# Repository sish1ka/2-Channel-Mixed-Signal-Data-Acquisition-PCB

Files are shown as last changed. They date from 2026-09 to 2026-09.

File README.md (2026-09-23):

# 2-Channel-Mixed-Signal-Data-Acquisition-PCB

## Overview

This project involves the design of a 2-channel mixed-signal data acquisition system intended to measure 0–5 V analog signals and convert them into digital data for microcontroller-based processing and analysis.

Each analog input passes through input protection, voltage scaling, buffering, and active low-pass filtering before being sampled by a 12-bit ADC on an STM32 microcontroller.

The system is being designed and simulated using LTspice and will be implemented as a 2-layer PCB using KiCad. In the future, Embedded C will be used for microcontroller data acquisition and MATLAB will be used for data analysis.

## Objectives

* Design a 2-channel analog data acquisition system
* Accept 0–5 V analog input signals
* Scale the input signals to an ADC-compatible voltage range
* Implement input protection against abnormal voltage excursions
* Buffer the analog signals to minimize loading between circuit stages
* Implement 2nd-order active low-pass filtering
* Sample the conditioned signals using a 12-bit ADC
* Transfer acquired data through UART
* Verify circuit behavior through simulation
* Design and verify a 2-layer PCB
* Analyze acquired data using MATLAB

## Tools

* LTspice
* KiCad
* C
* MATLAB
* Git / GitHub

## Circuit Design

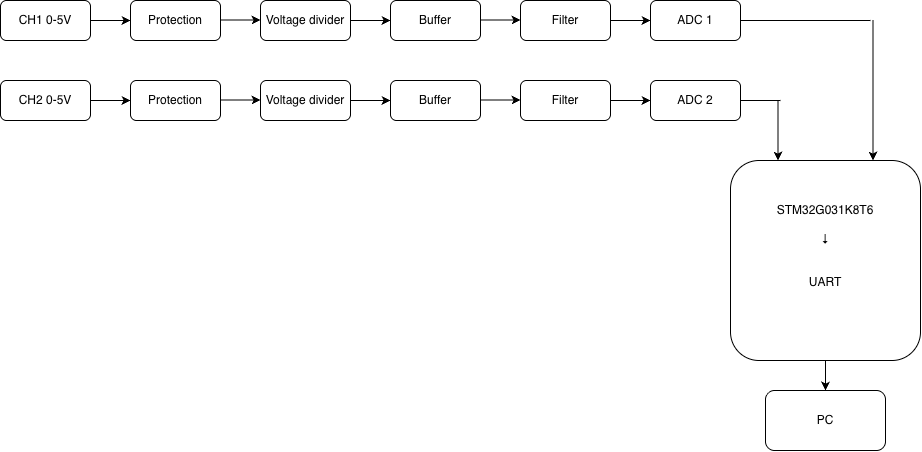
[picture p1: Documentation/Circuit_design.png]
Circuit Design


## Design Summary

| Parameter | Value |
| --- | ---: |
| Number of channels | 2 |
| Input signal | 0–5 V |
| ADC voltage range | 0–3.3 V |
| ADC resolution | 12-bit |
| Sampling rate | 4 kS/s/channel |
| Useful bandwidth | 0–100 Hz |
| Low-pass filter | 2nd-order Sallen-Key |
| Filter cutoff | ~297 Hz |
| Nominal system gain | ~0.60 V/V |
| Maximum nominal ADC input | ~3.0 V |
| Microcontroller | STM32G031K8T6 |
| Analog op-amp | MCP6004 |
| PCB layers | 2 |
| PCB dimensions | ~80 × 50 mm |
| UART baud rate | 460800 baud |z

## LTspice Simulation

### Verification Procedure

The analog front end is being verified using a node-by-node transient analysis.

Each verification step checks a specific electrical condition before proceeding to the next stage.

### 1. Voltage divider

**Purpose:**
Verify that the input protection resistor and voltage divider produce the expected scaled voltage for a 0–5 V input signal.

**Circuit Configuration:**

| Component | Value |
| --- | ---: |
| Input protection resistor | 1 kΩ |
| R_TOP | 16.5 kΩ |
| R_BOTTOM | 10 kΩ |

**Test Signal:**

```text
SINE(2.5 2.5 10)
```

The input signal has a 2.5 V DC offset, 2.5 V amplitude, and 10 Hz frequency, resulting in a 0–5 V input waveform.

**Transient Analysis:**

```text
.tran 100m
```

The 100 ms simulation window corresponds to one complete cycle of the 10 Hz input signal.

**Procedure:**

1. Apply the 0–5 V test signal to the input.
2. Run a transient analysis for 100 ms in LTspice.
3. Probe the input node.
4. Confirm that the input signal ranges from 0 V to 5 V.
5. Probe the output of the voltage divider.
6. Confirm that the scaled signal ranges from approximately 0 V to 1.82 V.

**Expected Result:**

| Parameter | Expected |
| --- | ---: |
| Input minimum | 0 V |
| Input maximum | 5 V |
| Scaled output minimum | ~0 V |
| Scaled output maximum |  ~1.82 V |

**Measured Result:**
`Vin = 0–5.00 V`
`Vscaled = 0–1.82 V`

**Result:** Pass

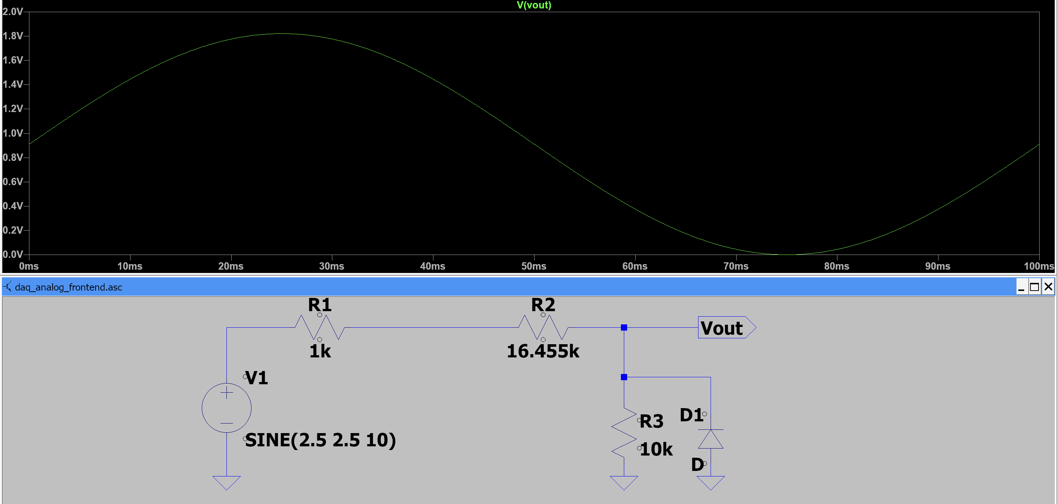
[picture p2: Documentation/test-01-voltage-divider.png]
Voltage Scaling Verification


### 2. Diode Voltage Protection Verification

**Purpose:**
Verify that the protection diode limits abnormal negative voltage excursions at the scaled node.

A bipolar test signal is applied to intentionally drive the input below the normal 0–5 V operating range.

**Test Signal:**

```text
SINE(0 5 10)
```

This produces a −5 V to +5 V input waveform.

**Procedure:**

1. Apply the bipolar test signal to the input.
2. Run a transient analysis for 100 ms in LTspice.
3. Probe the scaled node.
4. Observe the negative voltage excursion without the protection diode.
5. Enable the protection diode.
6. Repeat the simulation.
7. Compare the negative voltage excursion with and without the diode.

**Expected Result:**

The protection diode should conduct during the negative voltage excursion and limit the negative voltage at the protected node.

**Measured Result:**
Without the diode, the scaled node follows the negative input excursion. With the diode connected, the negative voltage is clamped and the scaled node no longer follows the negative excursion below the diode's forward-voltage region.

**Result:** Pass

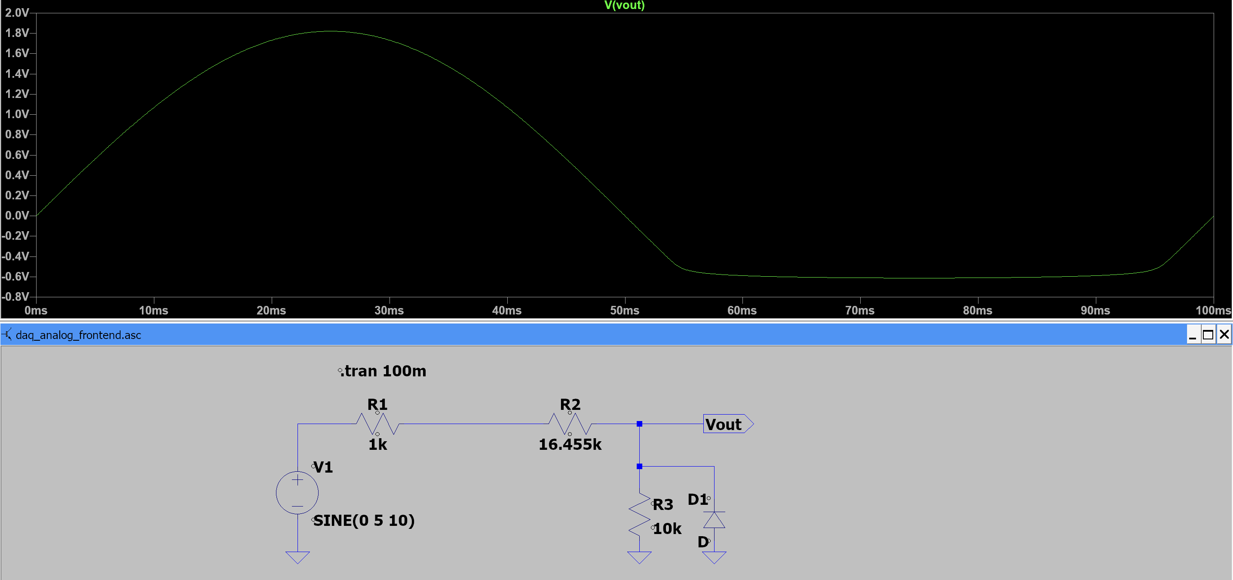
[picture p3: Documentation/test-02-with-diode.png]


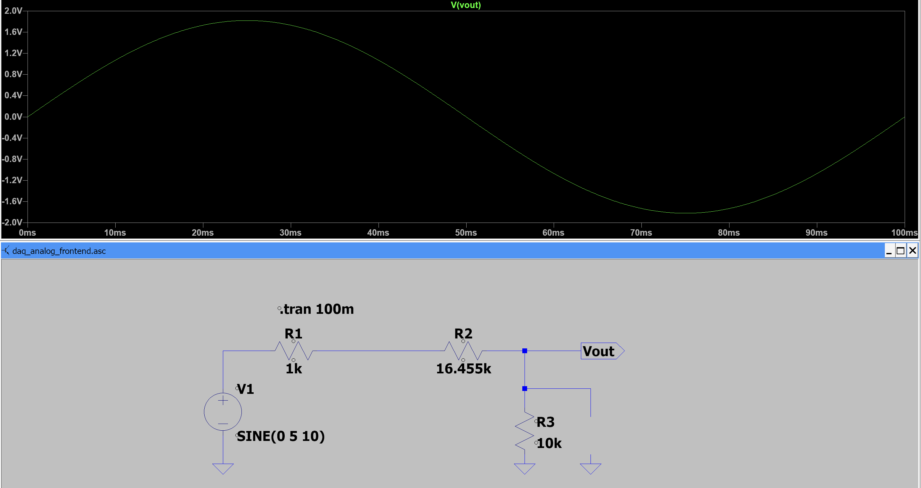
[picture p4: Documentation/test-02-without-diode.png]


### 3. Buffer Verification

**Purpose:**
Verify that the voltage buffer reproduces the scaled input signal without significantly changing its voltage level. The buffer also isolates the voltage divider from the following filter stage by providing high input impedance and low output impedance.

**Buffer Configuration:**

| Parameter | Value |
| --- | ---: |
| Op-Amp | UniversalOpamp2 |
| Configuration  | Voltage follower |
| Supply voltage | 3.3 V / 0 V |
| Buffer input | Voltage divider output |
| Buffer output  | Filter input |
| Feedback | Output directly connected to inverting input |

**Procedure:**

1. Apply the 0–5 V input signal using `SINE(2.5 2.5 10)`.
2. Run the transient simulation for 100 ms.
3. Measure the voltage at the output of the voltage divider.
4. Measure the voltage at the output of the buffer.
5. Compare the two waveforms over the full input cycle.

**Expected Result:**

The buffer output should closely follow the voltage-divider output with approximately unity voltage gain.

$$
A_v = \frac{V_{OUT}}{V_{IN}} \approx 1
$$

For the 0–5 V input signal, the voltage divider produces approximately 0–1.82 V. Therefore, the buffer output should also be approximately 0–1.82 V.

| Measurement | Expected Result |
| --- | ---: |
| Buffer input minimum  | ~0 V |
| Buffer input maximum  | ~1.82 V |
| Buffer output minimum | ~0 V |
| Buffer output maximum | ~1.82 V |
| Voltage gain | ~1 V/V |

**Measured Result:**

The buffer output closely follows the voltage-divider output. The buffer input and output waveforms overlap over the 0–1.82 V range, confirming that the voltage follower provides approximately unity gain without significantly altering the signal amplitude.

**Result:** Pass

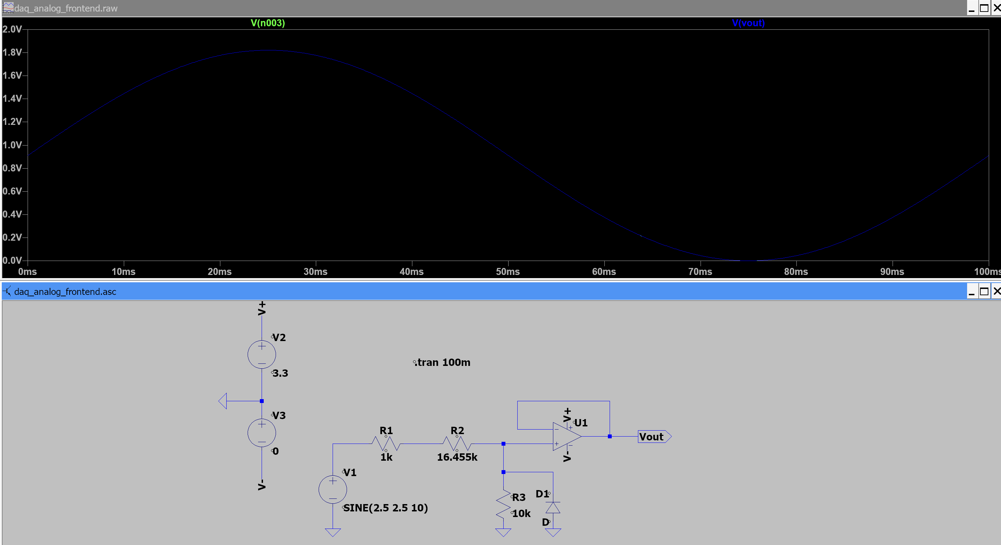
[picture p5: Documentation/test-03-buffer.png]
Buffer Verification


### 4. Sallen-Key Filter Response Verification

**Purpose:**
Verify that the Sallen-Key stage provides the intended second-order low-pass response, including the expected low-frequency gain, cutoff frequency, and roll-off behavior.

**Filter Configuration:**

| Parameter | Value |
| --- | ---: |
| R1 | 5.36 kΩ |
| R2 | 5.36 kΩ |
| C1 | 100 nF |
| C2 | 100 nF |
| Rf | 5.90 kΩ |
| Rg | 10 kΩ |
| Op-Amp Supply | 3.3 V / GND |

**Theoretical Low-Pass Cutoff:**

For equal resistor and capacitor values:

$$
f_c = \frac{1}{2\pi RC}
$$

$$
f_c = \frac{1}{2\pi(5.36\,k\Omega)(100\,nF)}
\approx 297\,Hz
$$

The Sallen-Key gain is:

$$
K = 1 + \frac{R_f}{R_g}
$$

$$
K = 1 + \frac{5.90\,k\Omega}{10\,k\Omega}
\approx 1.59
$$

The corresponding low-frequency magnitude is:

$$
20\log_{10}(1.59) \approx 4.03\,dB
$$

For a second-order low-pass filter, the cutoff frequency is approximately **3 dB below the passband magnitude**. Therefore, with a passband magnitude of approximately +4 dB, the expected magnitude at the cutoff is approximately +1 dB.

**Procedure:**

1. Set the LTspice input source to:

   * DC value: `2.5 V`
   * AC amplitude: `1 V`
   * AC phase: `0°`
2. Run an AC sweep using:
   `.ac dec 100 1 100k`
3. Plot the filter transfer function:
   `V(FILTER_OUT)/V(BUF_OUT)`
4. Measure the magnitude in the low-frequency passband.
5. Measure the magnitude near the theoretical cutoff frequency of 297 Hz.
6. Verify the expected attenuation beyond the cutoff region.

**Expected Result:**

| Measurement | Expected |
| --- | ---: |
| Low-frequency gain | ~1.59 V/V |
| Low-frequency magnitude | ~+4.03 dB |
| Cutoff frequency | ~297 Hz |
| Magnitude at cutoff | ~+1.03 dB |
| High-frequency roll-off | ~−40 dB/decade |

**Measured Result:**

* At **10 Hz:** approximately **+4 dB**
* At **297 Hz:** approximately **+1 dB**
* The measured response is consistent with the expected second-order low-pass behavior.

**Result:** Pass

The measured passband gain and attenuation at 297 Hz closely match the theoretical response. The filter therefore provides the intended low-pass behavior with a cutoff frequency of approximately 297 Hz.

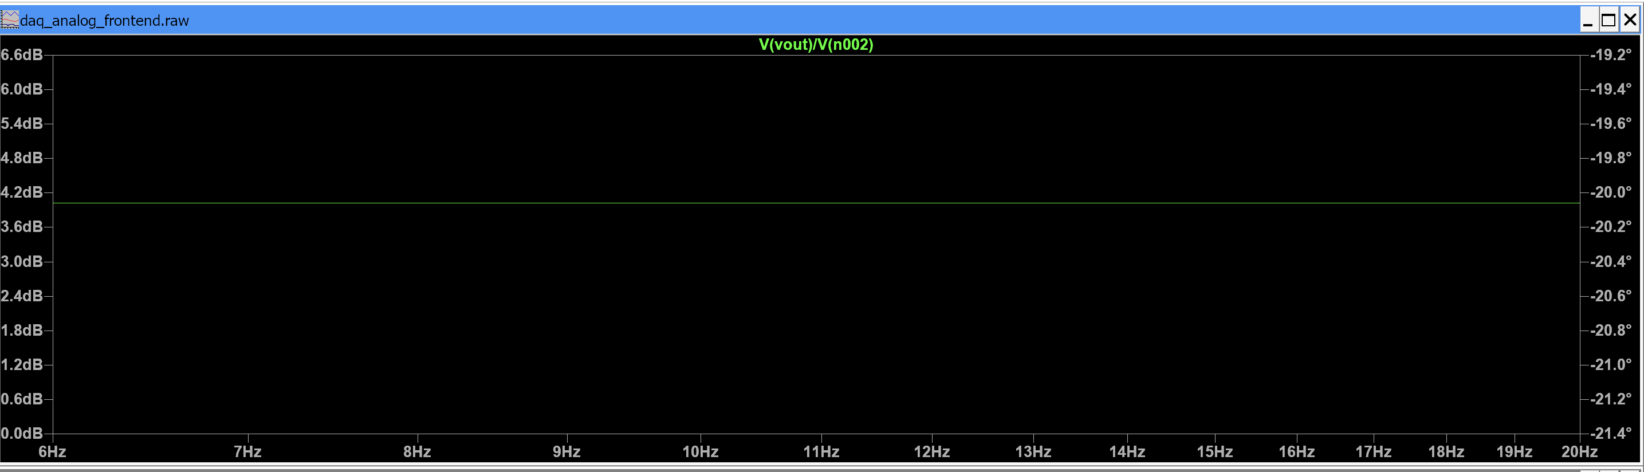
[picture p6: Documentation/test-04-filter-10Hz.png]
Sallen-Key Filter Response

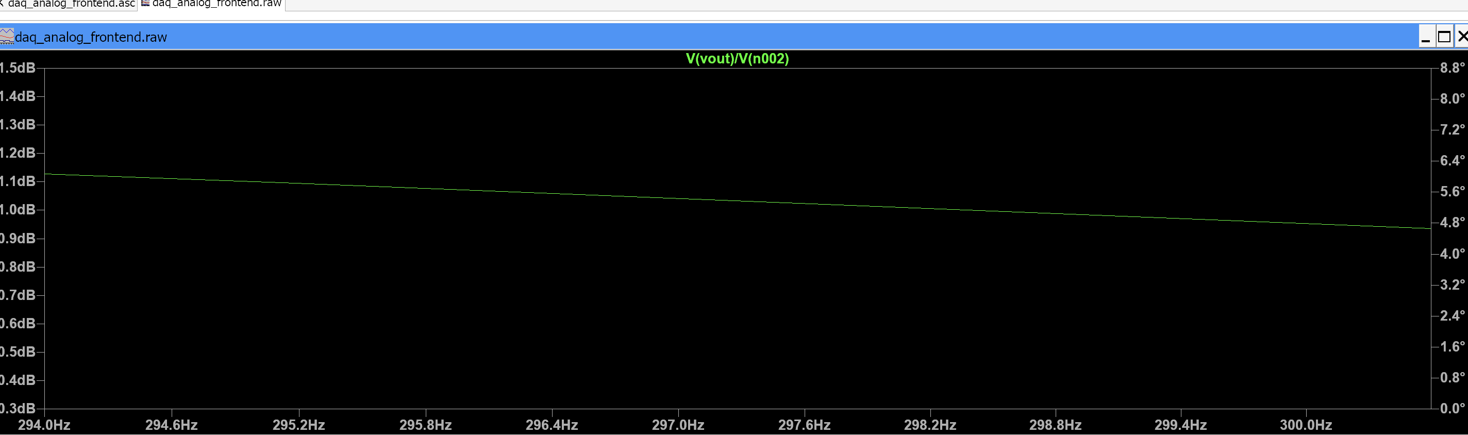
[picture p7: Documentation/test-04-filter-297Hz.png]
Sallen-Key Filter Response


### 5. ADC Input Range Verification

**Purpose:**
Verify that the conditioned analog signal remains within the STM32 ADC input range and that the complete analog front end provides the intended voltage scaling.

**ADC Configuration:**

| Parameter | Value |
| --- | ---: |
| ADC voltage range | 0–3.3 V |
| ADC resolution | 12-bit |
| Input signal | 0–5 V |
| ADC input filter | 47 Ω + 1 nF |
| Expected maximum ADC voltage | ~3.0 V |

**Procedure:**

1. Connect the Sallen-Key filter output to the ADC input through the 47 Ω series resistor.
2. Add a 1 nF capacitor from the ADC input node to GND.
3. Apply a 0–5 V sinusoidal input using:
   `SINE(2.5 2.5 10)`
4. Run a transient simulation using:
   `.tran 100m`
5. Plot the ADC input node voltage, `V(ADC_IN)`.
6. Verify that the ADC input remains within the 0–3.3 V operating range.

**Expected Result:**

For a 5 V maximum input, the nominal analog gain of approximately 0.60 V/V gives:

$$
V_{ADC,max} \approx 5V \times 0.60
$$

$$
V_{ADC,max} \approx 3.0V
$$

The ADC input should therefore remain below the 3.3 V supply while utilizing most of the available ADC range.

**Measured Result:**

The simulated ADC input waveform remained sinusoidal and reached approximately **2.9 V maximum** for a 5 V maximum input.

| Measurement | Result |
| --- | -----: |
| Input minimum | ~0 V |
| Input maximum | 5 V |
| ADC minimum | ~0 V |
| ADC maximum | ~2.9 V |
| ADC supply/reference |  3.3 V |

The maximum ADC voltage is approximately 0.4 V below the 3.3 V supply, providing headroom while maintaining a large usable portion of the ADC input range.

**Result:** Pass

The simulated ADC input remains within the 0–3.3 V range and is suitable for connection to the STM32 ADC.

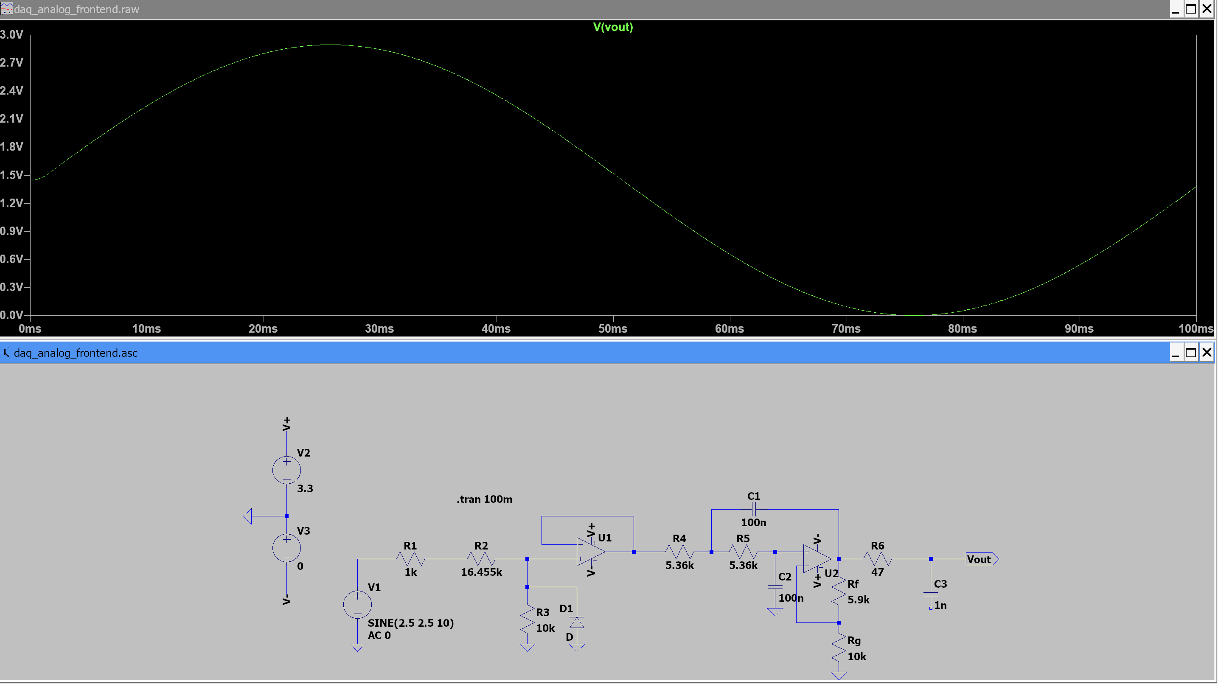
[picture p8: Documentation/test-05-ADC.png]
ADC Input Verification


### Results

| Verification | Theoretical | Measured | Error | Result |
| --- | --- | --- | ----: | --- |
| Voltage scaling | 0–1.89 V | 0–1.89 V | — | Pass |
| Negative voltage protection | Negative excursion clamped | Negative excursion clamped | — | Pass |
| Buffer | Unity gain | Unity gain | — | Pass |
| Filter cutoff | ~297 Hz | ~297 Hz | — | Pass |
| Complete analog chain | 0–3.0 V ADC input | 0–2.9 V ADC input | ~3.3% | Pass |

## PCB Design

The PCB was designed in KiCad based on the verified analog front-end and data acquisition circuit.

The board integrates two analog signal-conditioning channels with input protection, voltage scaling, signal conditioning, filtering, and a STM32G031K8Tx microcontroller interface.

### PCB Layout

* **Board size:** 80 × 50 mm
* **Design software:** KiCad
* **Layers:** 2-layer PCB
* **Analog channels:** 2
* **Main controller:** STM32G031K8Tx
* **Analog front-end:** MCP6004 quad op-amp
* **Mounting:** Through-hole and surface-mount components
* **Design verification:** Electrical Rules Check (ERC) and Design Rules Check (DRC)
* **Manufacturing outputs:** Gerber files and drill files generated from the final PCB layout

### Components

| Ref. | Component | Value | Qty. | Footprint |
| --- | --- | ---: | ---: | --- |
| C1, C2, C4, C5, C7, C8 | Ceramic Capacitor | 100 nF | 6 | `Capacitor_SMD:C_0805_2012Metric` |
| C3, C6 | Ceramic Capacitor | 1 nF | 2 | `Capacitor_SMD:C_0805_2012Metric` |
| D1, D2 | Diode | — | 2 | `Diode_SMD:D_SOD-123` |
| J1, J2 | 2-Pin Header | — | 2 | `Connector_PinHeader_2.54mm:PinHeader_1x02_P2.54mm_Vertical` |
| J3 | 5-Pin Header | — | 1 | `Connector_PinHeader_2.54mm:PinHeader_1x05_P2.54mm_Vertical` |
| J4 | 4-Pin Header | — | 1 | `Connector_PinHeader_2.54mm:PinHeader_1x04_P2.54mm_Vertical` |
| R1, R7 | Resistor | 1 kΩ | 2 | `Resistor_THT:R_Axial_DIN0207_L6.3mm_D2.5mm_P10.16mm_Horizontal` |
| R2, R8 | Resistor | 16.455 kΩ | 2 | `Resistor_THT:R_Axial_DIN0207_L6.3mm_D2.5mm_P10.16mm_Horizontal` |
| R3, R9, R13, Rg1, Rg2  | Resistor | 10 kΩ | 5 | `Resistor_THT:R_Axial_DIN0207_L6.3mm_D2.5mm_P10.16mm_Horizontal` |
| R4, R5, R10, R11 | Resistor | 5.36 kΩ | 4 | `Resistor_THT:R_Axial_DIN0207_L6.3mm_D2.5mm_P10.16mm_Horizontal` |
| R6, R12 | Resistor | 47 Ω | 2 | `Resistor_THT:R_Axial_DIN0207_L6.3mm_D2.5mm_P10.16mm_Horizontal` |
| Rf1, Rf2 | Resistor | 5.9 kΩ | 2 | `Resistor_THT:R_Axial_DIN0207_L6.3mm_D2.5mm_P10.16mm_Horizontal` |
| SW1 | Push Button | — | 1 | `Button_Switch_THT:SW_NKK_GW12LJP` |
| U1 | Quad Op-Amp | MCP6004 | 1 | `Package_DIP:DIP-14_W7.62mm` |
| U2 | Microcontroller | STM32G031K8Tx | 1 | `Package_QFP:LQFP-32_7x7mm_P0.8mm` |

**Total components:** 40

### Connector Pinout

Connector pin assignments are defined in the KiCad schematic.

| Connector | Pins | Function |
| --- | ---: | --- |
| J1 |  1–2 | Channel 1 interface |
| J2 |  1–2 | Channel 2 interface |
| J3 |  1–5 | Microcontroller / system interface |
| J4 |  1–4 | Power / system interface |

> **Note:** Refer to the KiCad schematic for the complete electrical pin assignments and net names.

### Power

The board does not include an onboard voltage regulator. The 3.3 V
rail (STM32 VDD/VDDA, MCP6004 V+) is supplied externally through
**J4 pin 1**, which is expected to be driven directly from a
regulated 3.3 V source — for example, the 3.3 V pin available on
many common USB-to-UART adapters (FTDI FT232RL, CP2102, etc.), or a
bench supply. This was a deliberate simplification to reduce
component count on a first custom board; a future revision could
add an onboard LDO (e.g. AMS1117-3.3) to accept a single unregulated
5 V input instead.

### Circuit Parameters

| Parameter | Value |
| --- | ---: |
| Supply Voltage | +3.3 V |
| Input Range | 0–5 V |
| ADC Range | 0–3.3 V |
| Sampling Rate | 4 kS/s/channel |
| Filter | 2nd-order Sallen-Key |
| Cutoff Frequency | ~297 Hz |

### KiCAD schematic

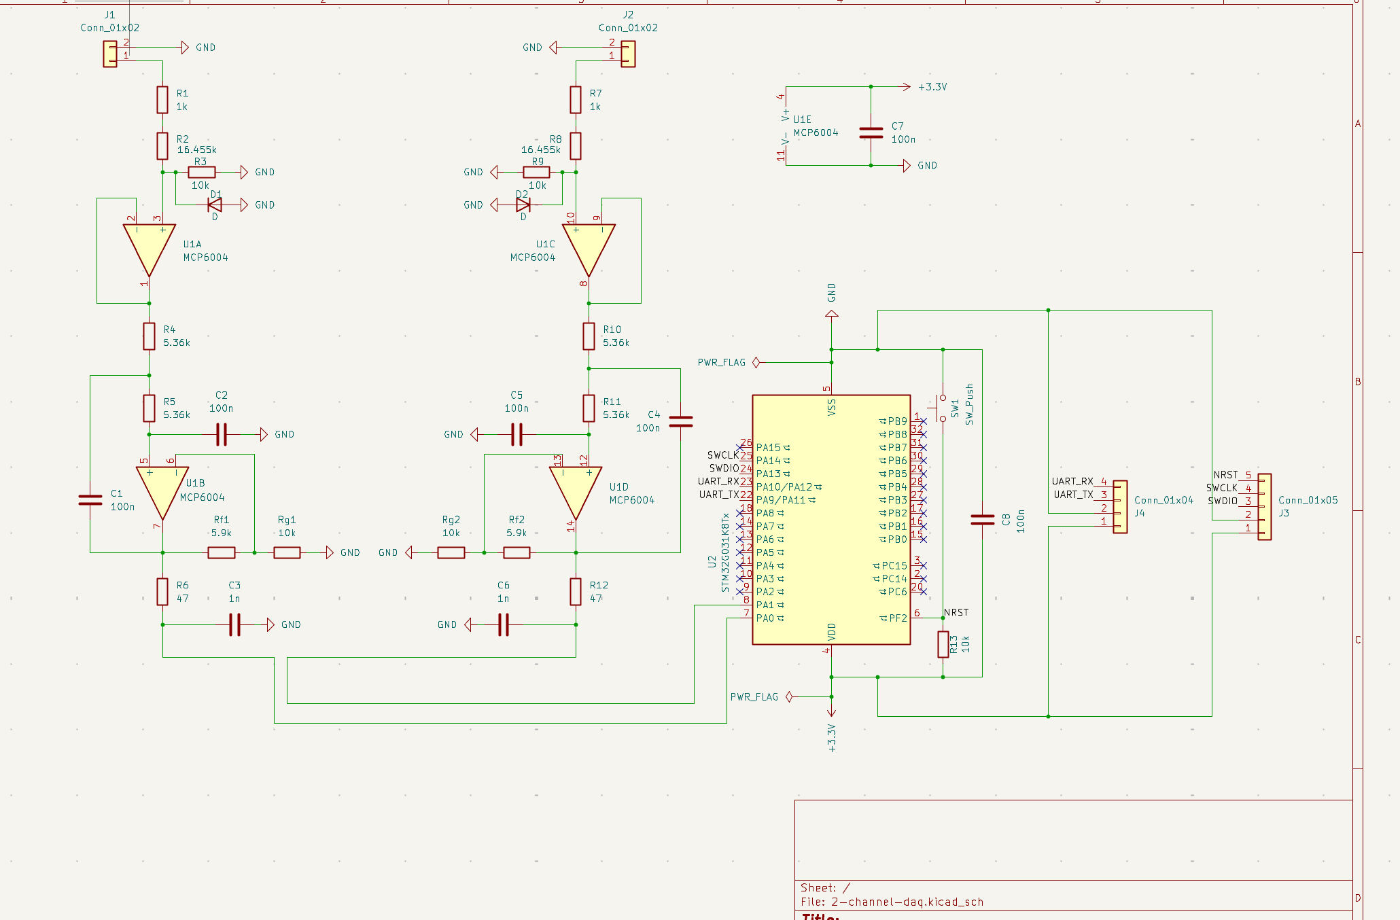
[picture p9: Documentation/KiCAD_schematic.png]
KiCAD schematic


### PCB Layout

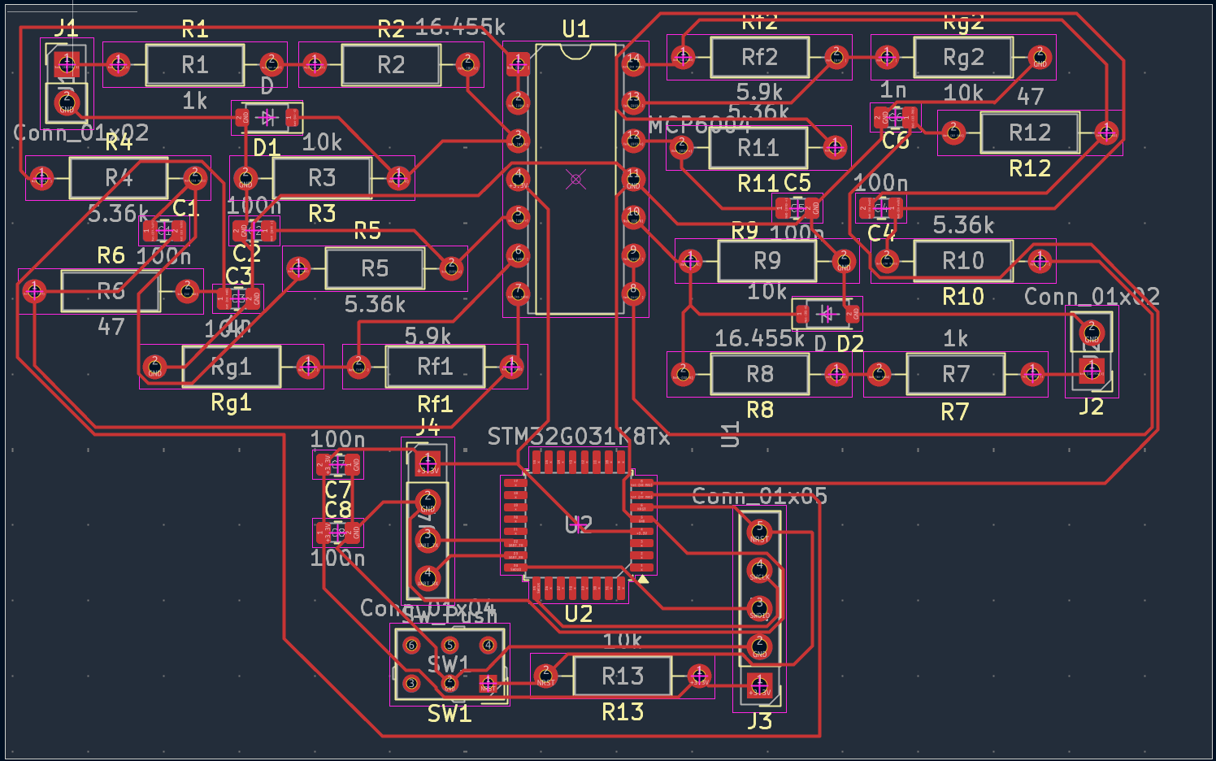
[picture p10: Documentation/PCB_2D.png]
2D\_PCB


### 3D View

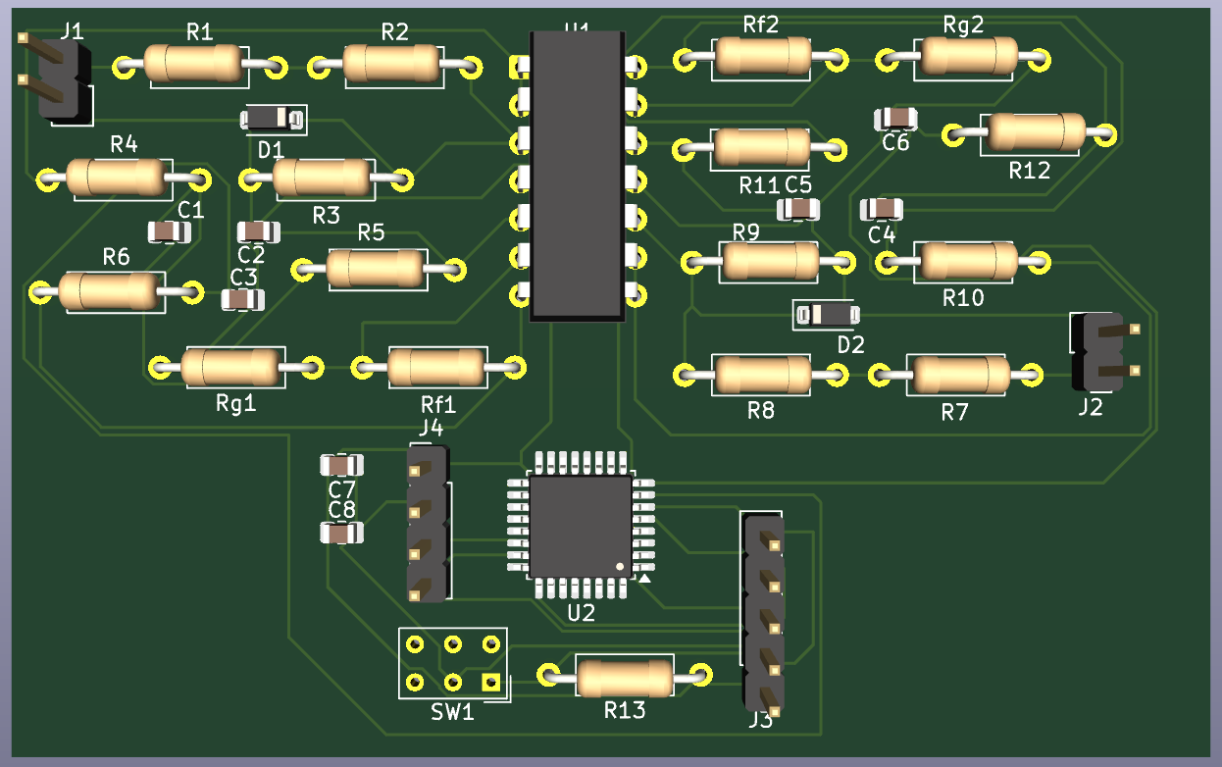
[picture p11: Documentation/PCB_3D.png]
3D PCB


### Fabrication Outputs

Gerber and drill files are generated using KiCad for PCB manufacturing.

The fabrication outputs include:

* Front and back copper
* Front and back solder mask
* Silkscreen
* Board outline
* Drill files

The generated files are available in `KiCad/Gerbers/`.

### PCB Design Verification

The PCB layout is checked using KiCad's Design Rules Checker (DRC).

**Target:**

* DRC errors: 0
* Unconnected items: 0
* Board outline: ~80 × 50 mm

## Firmware

**Status:** written and compiles cleanly against the STM32G0 HAL;
not flashed or tested on hardware (see Project Status above).

The firmware implements:

* Clock configuration: HSI16 + PLL → 64 MHz HCLK
* ADC1: 2 channels (PA0/PA1), 12-bit, scan mode
* TIM3: configured to trigger ADC conversions at 4 kHz
* DMA: circular-mode capture into a 256-sample ring buffer
  (128 channel-pairs), with half/full-transfer callbacks
* USART1: 460800 baud, TX via DMA
* A 9-byte binary frame protocol — sync bytes, sequence number,
  CH1/CH2 12-bit ADC codes, and an XOR checksum — for streaming
  samples to a host PC

## MATLAB Data Analysis

**Status:** written and tested (via GNU Octave) using synthetic data
matching the firmware's binary protocol; not yet run against real
captured hardware data.

* `filter_analysis.m` — computes the theoretical Sallen-Key frequency
  response directly from component values and can overlay an
  LTspice AC-sweep export for comparison. Runs standalone, no
  hardware needed.

## Future Work

If this project is picked back up:

1. Fabricate the PCB (JLCPCB/PCBWay, ~80×50mm 2-layer) and obtain an
   ST-Link programmer
2. Flash the firmware and verify each stage in isolation (GPIO →
   ADC polling → timer trigger → DMA → UART), per the staged
   bring-up plan this project was designed around
3. Fill in the DC accuracy, frequency-response, and noise
   measurement tables with real values, and compare against the
   LTspice/theoretical predictions already established
4. Consider adding an onboard 3.3 V LDO so the board accepts a
   single unregulated 5 V input

## Files

* `Documentation/` — design images and verification results
* `KiCad/` — schematic and PCB design files
* `LTspice/` — circuit simulations
* `Firmware/` — STM32 firmware
* `MATLAB/` — data analysis scripts
* `BOM/` — bill of materials
* `Gerbers/` — manufacturing outputs

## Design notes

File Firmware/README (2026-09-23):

What's implemented (main.c)
Clock: HSI16 + PLL → 64 MHz HCLK
ADC1: 2 channels (PA0/PA1), 12-bit, scan mode, triggered by TIM3
TIM3: configured for a 4 kHz sample-pair rate (64 MHz / 16000)
DMA: circular-mode ADC capture into a 256-sample ring buffer (128 channel-pairs), with half/full-complete callbacks
USART1: 460800 baud, TX via DMA
A 9-byte binary frame protocol (sync bytes, sequence number, CH1/CH2 12-bit codes, XOR checksum) matching the project spec

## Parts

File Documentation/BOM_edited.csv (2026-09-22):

## Bill of Materials (BOM)
 | Ref. | Component | Value | Qty. | Footprint
 | ---------------------- | ----------------- | ------------: | ---: | -----------------------------
 | C1, C2, C4, C5, C7, C8 | Ceramic Capacitor | 100 nF | 6 | 0805
 | C3, C6 | Ceramic Capacitor | 1 nF | 2 | 0805
 | D1, D2 | Diode | — | 2 | SOD-123
 | J1, J2 | 2-Pin Header | — | 2 | 1×02, 2.54 mm
 | J3 | 5-Pin Header | — | 1 | 1×05, 2.54 mm
 | J4 | 4-Pin Header | — | 1 | 1×04, 2.54 mm
 | R1, R7 | Resistor | 1 kΩ | 2 | DIN0207, 10.16 mm pitch
 | R2, R8 | Resistor | 16.455 kΩ | 2 | DIN0207, 10.16 mm pitch
 | R3, R9, R13, Rg1, Rg2 | Resistor | 10 kΩ | 5 | DIN0207, 10.16 mm pitch
 | R4, R5, R10, R11 | Resistor | 5.36 kΩ | 4 | DIN0207, 10.16 mm pitch
 | R6, R12 | Resistor | 47 Ω | 2 | DIN0207, 10.16 mm pitch
 | Rf1, Rf2 | Resistor | 5.9 kΩ | 2 | DIN0207, 10.16 mm pitch
 | SW1 | Push Button | — | 1 | NKK GW12LJP
 | U1 | Quad Op-Amp | MCP6004 | 1 | DIP-14, 7.62 mm
 | U2 | Microcontroller | STM32G031K8Tx | 1 | LQFP-32, 7×7 mm, 0.8 mm pitch
**Total components:** 40

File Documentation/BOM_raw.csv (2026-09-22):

Id | Designator | Footprint | Quantity | Designation | Supplier and ref
1 | C1, C2, C4, C5, C7, C8 | C_0805_2012Metric | 6 | 100n
2 | C3, C6 | C_0805_2012Metric | 2 | 1n
3 | D1, D2 | D_SOD-123 | 2 | D
4 | J1, J2 | PinHeader_1x02_P2.54mm_Vertical | 2 | Conn_01x02
5 | J3 | PinHeader_1x05_P2.54mm_Vertical | 1 | Conn_01x05
6 | J4 | PinHeader_1x04_P2.54mm_Vertical | 1 | Conn_01x04
7 | R1, R7 | R_Axial_DIN0207_L6.3mm_D2.5mm_P10.16mm_Horizontal | 2 | 1k
8 | R2, R8 | R_Axial_DIN0207_L6.3mm_D2.5mm_P10.16mm_Horizontal | 2 | 16.455k
9 | R3, R9, R13, Rg1, Rg2 | R_Axial_DIN0207_L6.3mm_D2.5mm_P10.16mm_Horizontal | 5 | 10k
10 | R4, R5, R10, R11 | R_Axial_DIN0207_L6.3mm_D2.5mm_P10.16mm_Horizontal | 4 | 5.36k
11 | R6, R12 | R_Axial_DIN0207_L6.3mm_D2.5mm_P10.16mm_Horizontal | 2 | 47
12 | Rf1, Rf2 | R_Axial_DIN0207_L6.3mm_D2.5mm_P10.16mm_Horizontal | 2 | 5.9k
13 | SW1 | SW_NKK_GW12LJP | 1 | SW_Push
14 | U1 | DIP-14_W7.62mm | 1 | MCP6004
15 | U2 | LQFP-32_7x7mm_P0.8mm | 1 | STM32G031K8Tx

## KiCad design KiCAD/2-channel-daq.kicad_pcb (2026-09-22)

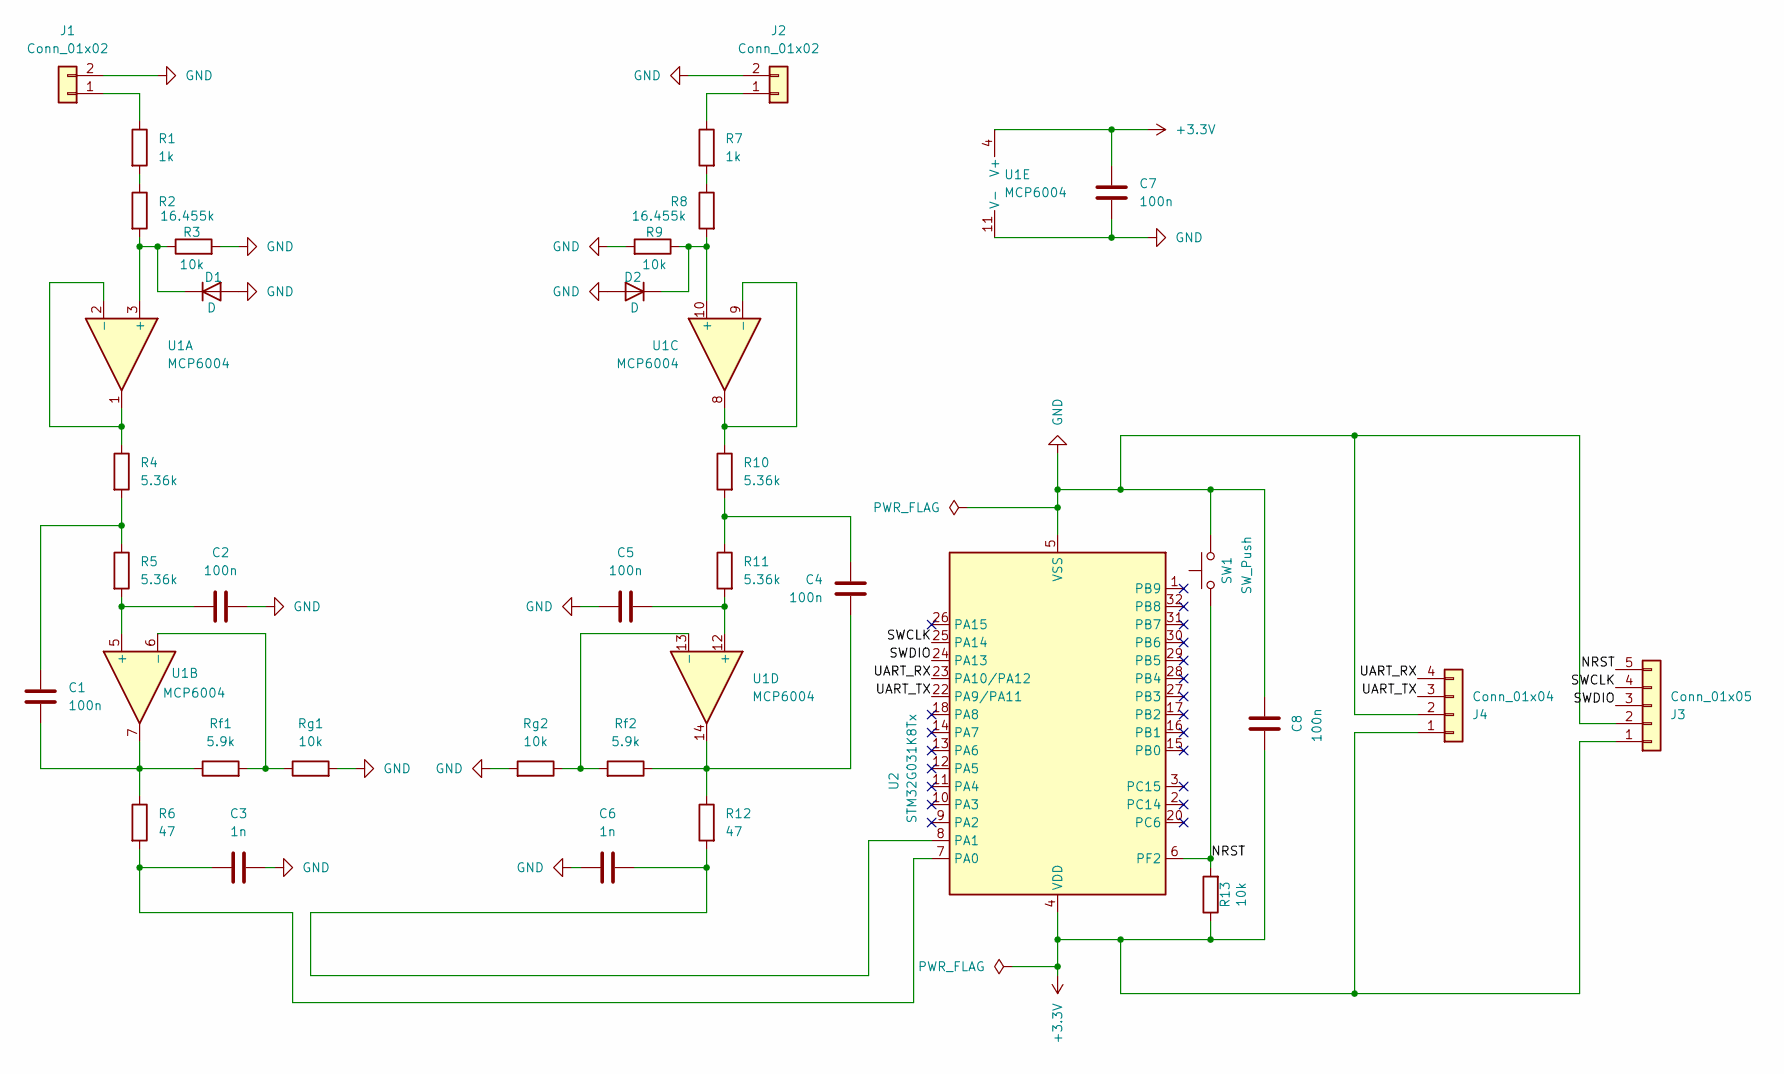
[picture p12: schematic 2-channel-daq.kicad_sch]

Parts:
C1, C2, C4, C5, C7, C8: 100n; C_0805_2012Metric
C3, C6: 1n; C_0805_2012Metric
D1, D2: D; D_SOD-123
J1, J2: Conn_01x02; PinHeader_1x02_P2.54mm_Vertical
J3: Conn_01x05; PinHeader_1x05_P2.54mm_Vertical
J4: Conn_01x04; PinHeader_1x04_P2.54mm_Vertical
R1, R7: 1k; R_Axial_DIN0207_L6.3mm_D2.5mm_P10.16mm_Horizontal
R2, R8: 16.455k; R_Axial_DIN0207_L6.3mm_D2.5mm_P10.16mm_Horizontal
R3, R9, R13: 10k; R_Axial_DIN0207_L6.3mm_D2.5mm_P10.16mm_Horizontal
R4, R5, R10, R11: 5.36k; R_Axial_DIN0207_L6.3mm_D2.5mm_P10.16mm_Horizontal
R6, R12: 47; R_Axial_DIN0207_L6.3mm_D2.5mm_P10.16mm_Horizontal
Rf1, Rf2: 5.9k; R_Axial_DIN0207_L6.3mm_D2.5mm_P10.16mm_Horizontal
Rg1, Rg2: 10k; R_Axial_DIN0207_L6.3mm_D2.5mm_P10.16mm_Horizontal
SW1: SW_Push; SW_NKK_GW12LJP
U1: MCP6004; DIP-14_W7.62mm
U2: STM32G031K8Tx; LQFP-32_7x7mm_P0.8mm

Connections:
+3.3V: C7.2, C8.1, J3.1, J4.1, R13.1, U1.4 (V+), U2.4 (VDD)
/NRST: J3.5, R13.2, SW1.1, U2.6 (PF2)
/SWCLK: J3.4, U2.25 (PA14)
/SWDIO: J3.3, U2.24 (PA13)
/UART_RX: J4.4, U2.23 (PA10/PA12)
/UART_TX: J4.3, U2.22 (PA9/PA11)
GND: C2.2, C3.2, C5.2, C6.2, C7.1, C8.2, D1.2 (A), D2.2 (A), J1.2, J2.2, J3.2, J4.2, R3.2, R9.2, Rg1.2, Rg2.2, SW1.2, U1.11 (V-), U2.5 (VSS)
unnamed: C1.1, R4.2, R5.1
unnamed: C1.2, R6.1, Rf1.1, U1.7
unnamed: C4.1, R10.2, R11.1
unnamed: C4.2, R12.1, Rf2.1, U1.14
unnamed: D1.1 (K), R2.2, R3.1, U1.3 (+)
unnamed: D2.1 (K), R8.2, R9.1, U1.10 (+)
unnamed: J1.1, R1.1
unnamed: J2.1, R7.1
unnamed: R1.2, R2.1
unnamed: R7.2, R8.1
unnamed: R4.1, U1.1, U1.2 (-)
unnamed: C2.1, R5.2, U1.5 (+)
unnamed: Rf1.2, Rg1.1, U1.6 (-)
unnamed: R10.1, U1.8, U1.9 (-)
unnamed: C5.1, R11.2, U1.12 (+)
unnamed: Rf2.2, Rg2.1, U1.13 (-)
unnamed: C3.1, R6.2, U2.7 (PA0)
unnamed: C6.1, R12.2, U2.8 (PA1)

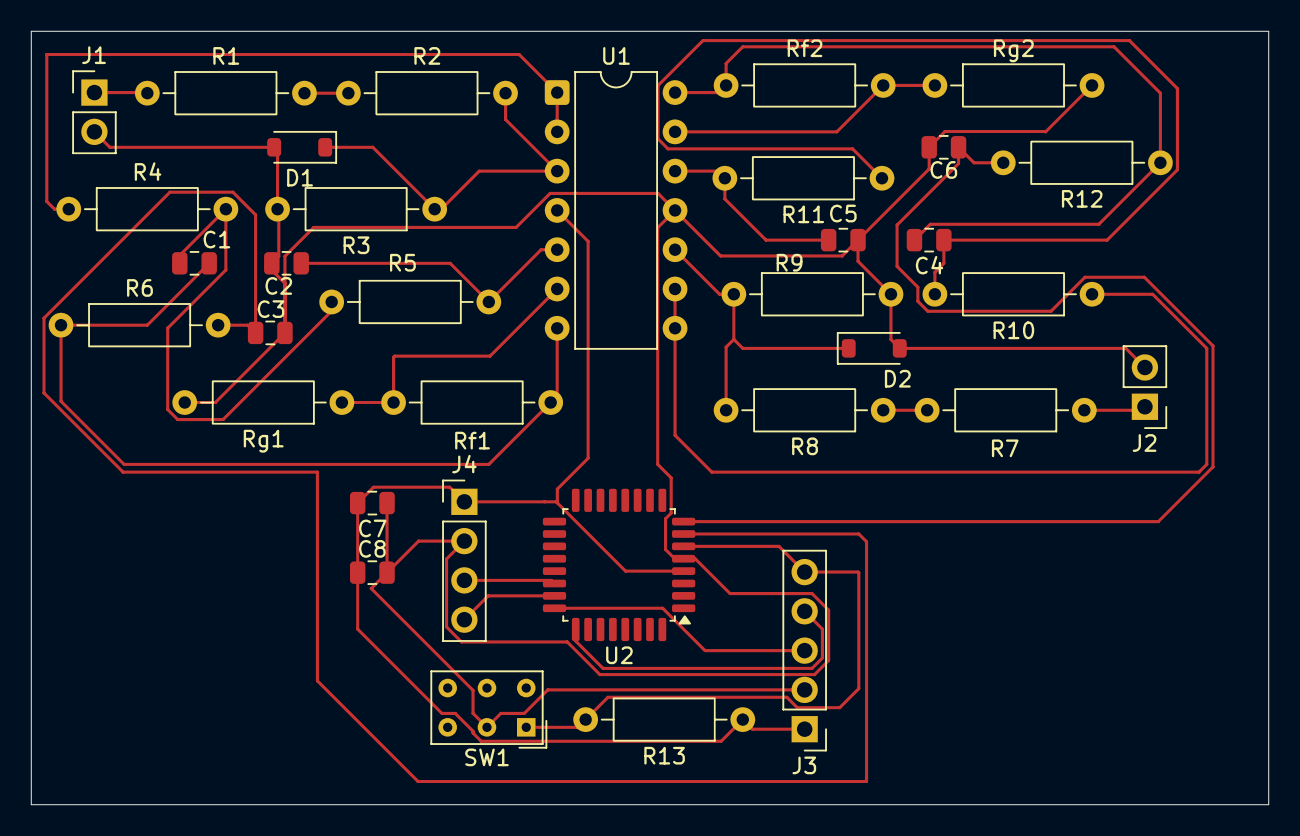
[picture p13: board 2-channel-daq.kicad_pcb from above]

Board: 2 copper layers, 80.0 x 50.0 mm, 34 parts (0 on the bottom side), 25 nets.

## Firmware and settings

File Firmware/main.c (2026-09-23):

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
/* Includes ------------------------------------------------------------------*/
#include "main.h"
#include <string.h>

/* USER CODE BEGIN PTD */

/* Binary UART frame, 9 bytes total, matches project spec section 69 */
#pragma pack(push, 1)
typedef struct
{
  uint8_t  sync0;      /* 0xA5 */
  uint8_t  sync1;       /* 0x5A */
  uint16_t seq;          /* sample sequence number */
  uint16_t ch1;           /* CH1 raw 12-bit ADC code */
  uint16_t ch2;            /* CH2 raw 12-bit ADC code */
  uint8_t  checksum;        /* XOR of seq_l..ch2_h */
} daq_frame_t;
#pragma pack(pop)

/* USER CODE END PTD */

/* USER CODE BEGIN PD */

#define ADC_BUF_LEN     256U    /* 128 channel-pairs (CH1,CH2 interleaved) */
#define FRAME_SYNC0     0xA5U
#define FRAME_SYNC1     0x5AU

/* USER CODE END PD */

ADC_HandleTypeDef hadc1;
DMA_HandleTypeDef hdma_adc1;

TIM_HandleTypeDef htim3;

UART_HandleTypeDef huart1;
DMA_HandleTypeDef hdma_usart1_tx;

/* USER CODE BEGIN PV */

static uint16_t adc_buffer[ADC_BUF_LEN];

static volatile uint8_t half_ready = 0;
static volatile uint8_t full_ready = 0;

static uint16_t sample_seq = 0;
static daq_frame_t tx_frame;
static volatile uint8_t uart_busy = 0;

/* USER CODE END PV */

void SystemClock_Config(void);
static void MX_GPIO_Init(void);
static void MX_DMA_Init(void);
static void MX_ADC1_Init(void);
static void MX_TIM3_Init(void);
static void MX_USART1_UART_Init(void);
/* USER CODE BEGIN PFP */

static uint8_t  ComputeChecksum(const daq_frame_t *f);
static void     BuildAndSendFrame(uint16_t ch1_code, uint16_t ch2_code);
static void     ProcessHalfBuffer(uint16_t *buf_half);

/* USER CODE END PFP */

/* USER CODE BEGIN 0 */

/**
  * @brief  XOR checksum over seq_l, seq_h, ch1_l, ch1_h, ch2_l, ch2_h.
  *         Matches project spec section 71.
  */
static uint8_t ComputeChecksum(const daq_frame_t *f)
{
  uint8_t seq_l = (uint8_t)(f->seq & 0xFF);
  uint8_t seq_h = (uint8_t)((f->seq >> 8) & 0xFF);
  uint8_t ch1_l = (uint8_t)(f->ch1 & 0xFF);
  uint8_t ch1_h = (uint8_t)((f->ch1 >> 8) & 0xFF);
  uint8_t ch2_l = (uint8_t)(f->ch2 & 0xFF);
  uint8_t ch2_h = (uint8_t)((f->ch2 >> 8) & 0xFF);

  return (uint8_t)(seq_l ^ seq_h ^ ch1_l ^ ch1_h ^ ch2_l ^ ch2_h);
}

/**
  * @brief  Pack one sample pair into a binary frame and transmit over
  *         UART via DMA. Blocks briefly if the previous frame is still
  *         being sent (uart_busy) rather than overwriting tx_frame mid-DMA.
  */
static void BuildAndSendFrame(uint16_t ch1_code, uint16_t ch2_code)
{
  /* Guard against clobbering an in-flight DMA TX buffer. At 4 kHz frame
   * rate and 460800 baud, a 9-byte frame takes ~195 us to transmit, well
   * under the 250 us sample period, so this should rarely if ever stall.
   */
  uint32_t timeout = 1000U;
  while (uart_busy && timeout--)
  {
    /* busy-wait; replace with a queue/ring buffer if this becomes an
     * issue once measured on real hardware */
  }

  tx_frame.sync0 = FRAME_SYNC0;
  tx_frame.sync1 = FRAME_SYNC1;
  tx_frame.seq   = sample_seq++;
  tx_frame.ch1   = ch1_code;
  tx_frame.ch2   = ch2_code;
  tx_frame.checksum = ComputeChecksum(&tx_frame);

  uart_busy = 1;
  HAL_UART_Transmit_DMA(&huart1, (uint8_t *)&tx_frame, sizeof(tx_frame));
}

/**
  * @brief  Walk one half of the circular ADC buffer (64 uint16_t = 32
  *         channel-pairs) and ship each pair as a frame.
  * @param  buf_half Pointer to the first sample of the half to process.
  */
static void ProcessHalfBuffer(uint16_t *buf_half)
{
  const uint16_t pairs_per_half = (ADC_BUF_LEN / 2U) / 2U; /* = 64 */

  for (uint16_t i = 0; i < pairs_per_half; i++)
  {
    uint16_t ch1_code = buf_half[(i * 2U) + 0U];
    uint16_t ch2_code = buf_half[(i * 2U) + 1U];
    BuildAndSendFrame(ch1_code, ch2_code);
  }
}

/* USER CODE END 0 */

/**
  * @brief  The application entry point.
  * @retval int
  */
int main(void)
{

  /* MCU Configuration--------------------------------------------------------*/
  HAL_Init();

  /* Configure the system clock */
  SystemClock_Config();

  /* Initialize all configured peripherals */
  MX_GPIO_Init();
  MX_DMA_Init();
  MX_ADC1_Init();
  MX_TIM3_Init();
  MX_USART1_UART_Init();
  /* USER CODE BEGIN 2 */

  /* Calibrate ADC before first use — recommended by ST for accuracy */
  if (HAL_ADCEx_Calibration_Start(&hadc1) != HAL_OK)
  {
    Error_Handler();
  }

  /* Start the sample-rate timer (TIM3 TRGO drives ADC conversions) */
  if (HAL_TIM_Base_Start(&htim3) != HAL_OK)
  {
    Error_Handler();
  }

  /* Start ADC in circular DMA mode. TIM3 TRGO paces each conversion
   * pair at 4 kHz; DMA moves each 16-bit result into adc_buffer and
   * wraps automatically at ADC_BUF_LEN. */
  if (HAL_ADC_Start_DMA(&hadc1, (uint32_t *)adc_buffer, ADC_BUF_LEN) != HAL_OK)
  {
    Error_Handler();
  }

  /* USER CODE END 2 */

  /* Infinite loop */
  /* USER CODE BEGIN WHILE */
  while (1)
  {
    if (half_ready)
    {
      half_ready = 0;
      ProcessHalfBuffer(&adc_buffer[0]);
    }

    if (full_ready)
    {
      full_ready = 0;
      ProcessHalfBuffer(&adc_buffer[ADC_BUF_LEN / 2U]);
    }

    /* USER CODE END WHILE */

    /* USER CODE BEGIN 3 */
  }
  /* USER CODE END 3 */
}

/**
  * @brief  ADC DMA half-transfer callback — first half of adc_buffer
  *         (samples 0..127, i.e. 64 channel-pairs) is ready.
  */
void HAL_ADC_ConvHalfCpltCallback(ADC_HandleTypeDef *hadc)
{
  half_ready = 1;
}

/**
  * @brief  ADC DMA full-transfer callback — second half of adc_buffer
  *         is ready. DMA wraps and keeps filling the first half again.
  */
void HAL_ADC_ConvCpltCallback(ADC_HandleTypeDef *hadc)
{
  full_ready = 1;
}

/**
  * @brief  UART TX DMA complete callback — clears the busy flag so the
  *         next frame can be built/sent.
  */
void HAL_UART_TxCpltCallback(UART_HandleTypeDef *huart)
{
  if (huart->Instance == USART1)
  {
    uart_busy = 0;
  }
}

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
